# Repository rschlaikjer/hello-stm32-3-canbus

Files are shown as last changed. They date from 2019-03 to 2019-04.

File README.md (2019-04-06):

# STM32 Programming with opencm3: Part 3

This repository contains the complete companion code and KiCad design files
to accompany
[this blog post](https://rhye.org/post/stm32-with-opencm3-3-canbus/)
which works through using the CAN Bus on an STM32 series MCU.

You can also check out the three previous posts in the series:

- [Compiling and Uploading](https://rhye.org/post/stm32-with-opencm3-0-compiling-and-uploading/),
- [Alternate Functions and USARTs](https://rhye.org/post/stm32-with-opencm3-1-usart-and-printf/)
- [SPI and DMA](https://rhye.org/post/stm32-with-opencm3-2-spi-and-dma/)

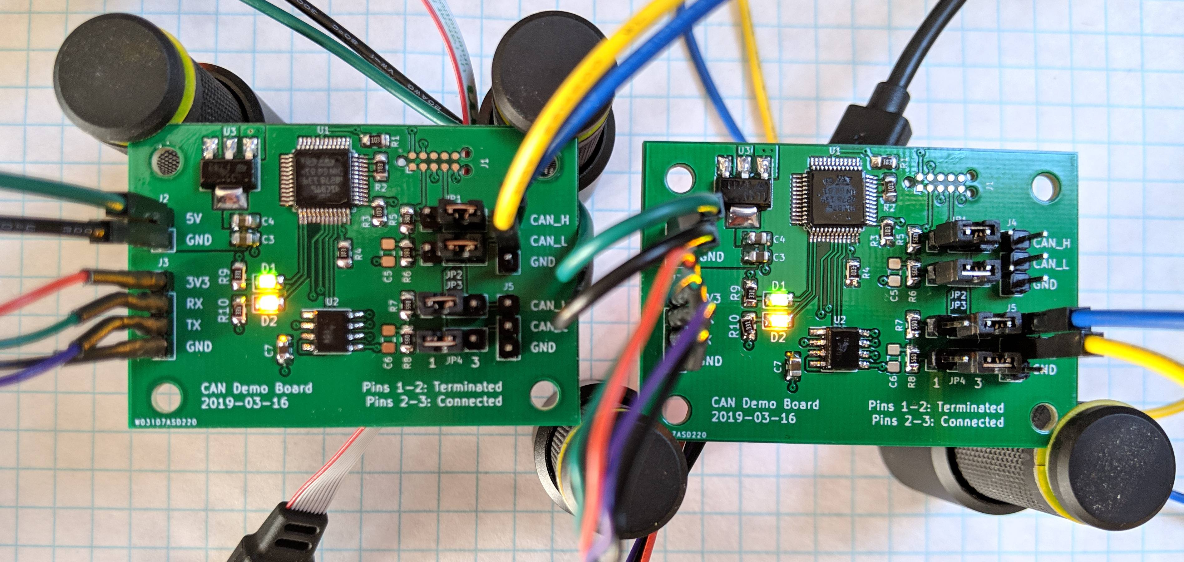
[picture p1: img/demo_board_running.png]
Blink Blink


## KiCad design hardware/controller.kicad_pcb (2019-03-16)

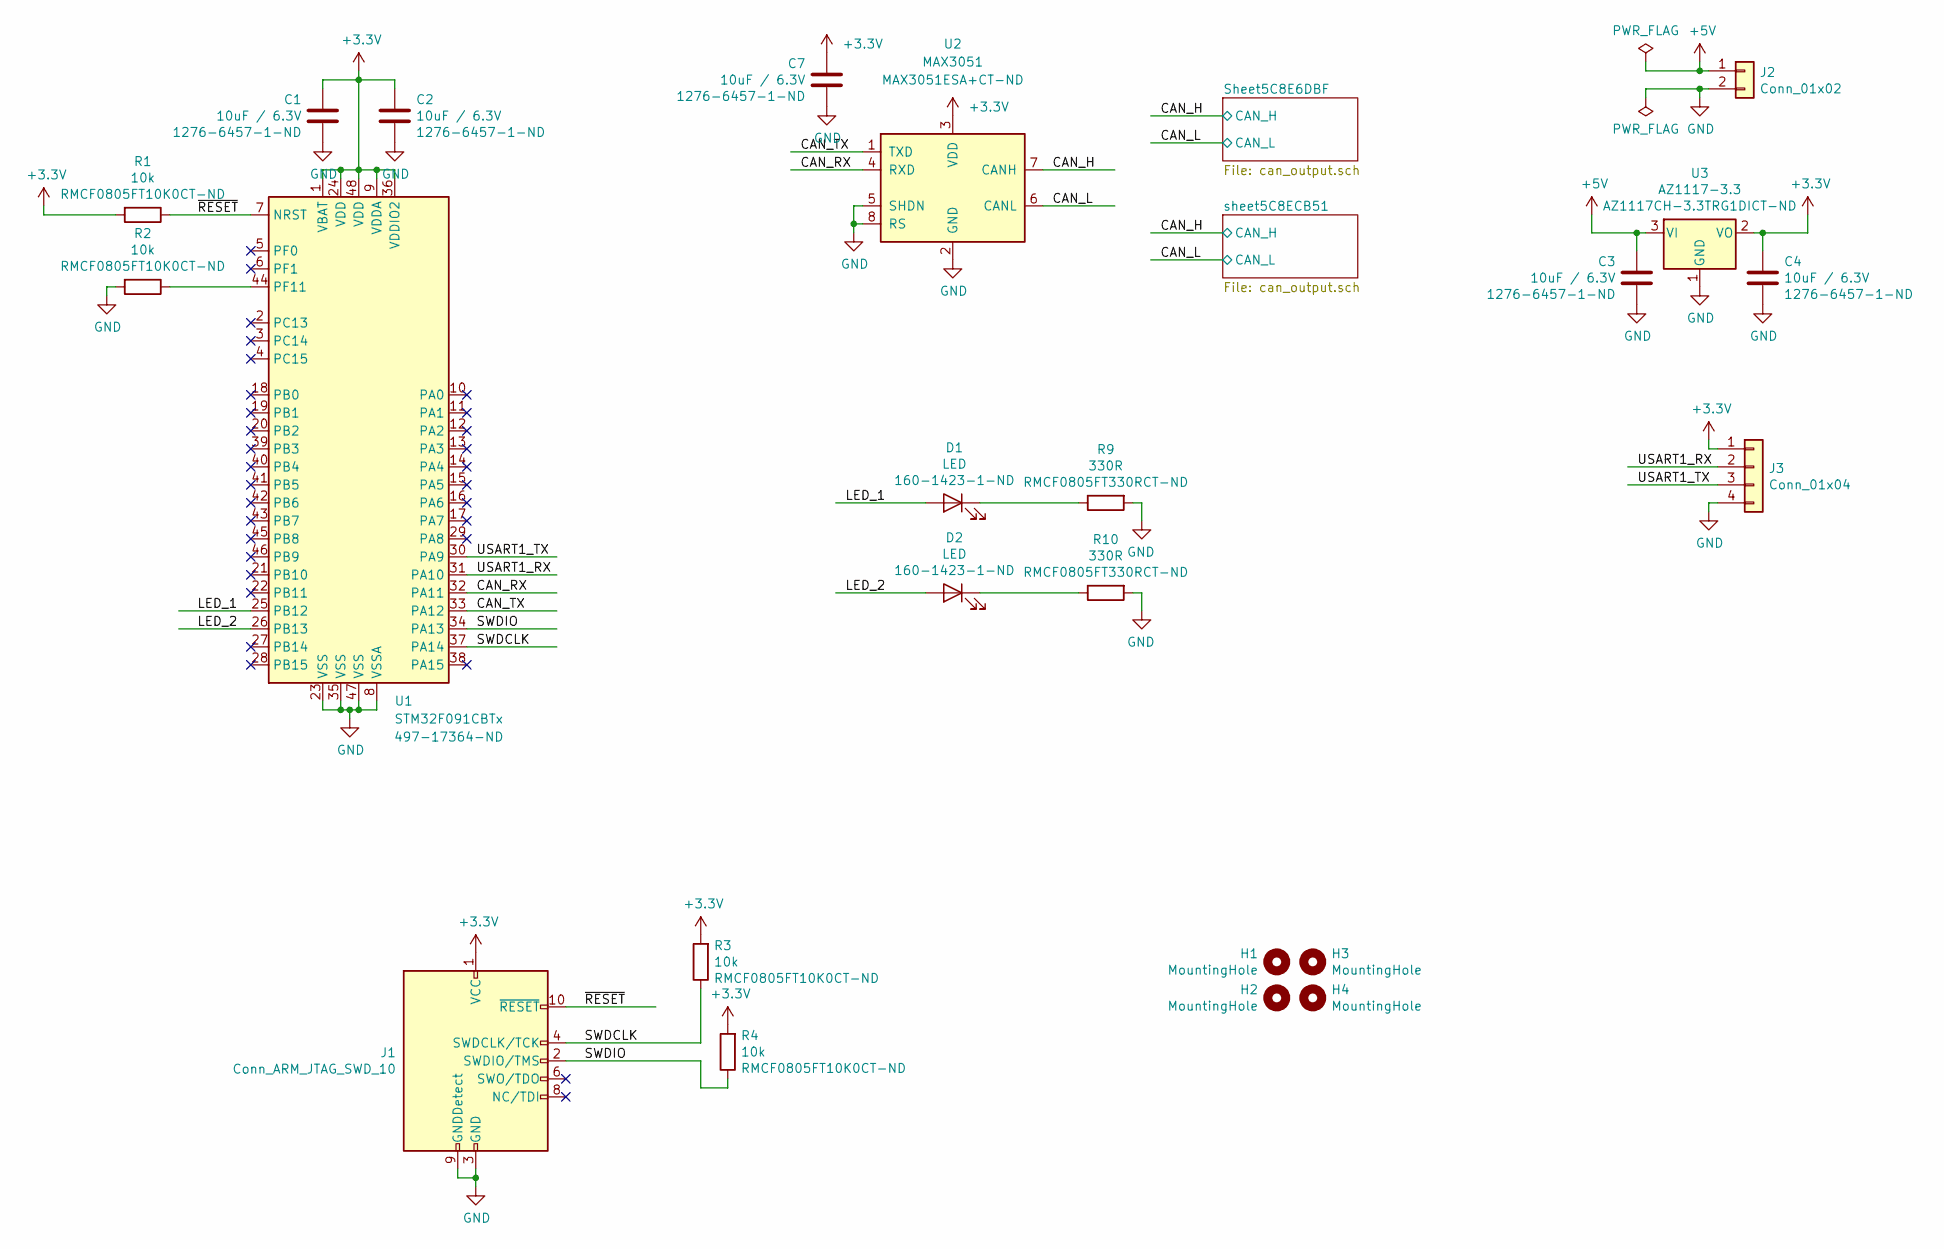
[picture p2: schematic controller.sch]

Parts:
C1, C2, C3, C4, C7: 10uF / 6.3V; C_0805_2012Metric_Pad1.15x1.40mm_HandSolder; Manufacturer PN CL21A106KQFNNNG; DigiKey PN 1276-6457-1-ND
D1, D2: LED; LED_0805_2012Metric_Pad1.15x1.40mm_HandSolder; Manufacturer PN LTST-C171GKT; DigiKey PN 160-1423-1-ND
H1, H2, H3, H4: MountingHole; MountingHole_3.2mm_M3
J1: Conn_ARM_JTAG_SWD_10; Tag-Connect_TC2050-IDC-NL_2x05_P1.27mm_Vertical
J2: Conn_01x02; PinHeader_1x02_P2.54mm_Vertical
J3: Conn_01x04; PinHeader_1x04_P2.54mm_Vertical
R1, R2, R3, R4: 10k; R_0805_2012Metric_Pad1.15x1.40mm_HandSolder; Manufacturer PN RMCF0805FT10K0; DigiKey PN RMCF0805FT10K0CT-ND
R9, R10: 330R; R_0805_2012Metric_Pad1.15x1.40mm_HandSolder; Manufacturer PN RMCF0805FT330R; DigiKey PN RMCF0805FT330RCT-ND
U1: STM32F091CBTx; LQFP-48_7x7mm_P0.5mm; Manufacturer PN STM32F091CBT6; DigiKey PN 497-17364-ND
U2: MAX3051; SOIC-8_3.9x4.9mm_P1.27mm; Manufacturer PN MAX3051ESA+T; DigiKey PN MAX3051ESA+CT-ND
U3: AZ1117-3.3; SOT-223; Manufacturer PN AZ1117CH-3.3TRG1; DigiKey PN AZ1117CH-3.3TRG1DICT-ND

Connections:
+3V3: C1.2, C2.1, C4.2, C7.1, J1.1 (VCC), J3.1, R1.2, R3.2, R4.2, U1.1 (VBAT), U1.9 (VDDA), U1.24 (VDD), U1.36 (VDDIO2), U1.48 (VDD), U2.3 (VDD), U3.2 (VO)
+5V: C3.2, J2.1, U3.3 (VI)
/CAN_H: U2.7 (CANH); also elsewhere on the board
/CAN_L: U2.6 (CANL); also elsewhere on the board
/CAN_RX: U1.32 (PA11), U2.4 (RXD)
/CAN_TX: U1.33 (PA12), U2.1 (TXD)
/LED_1: D1.2 (A), U1.25 (PB12)
/LED_2: D2.2 (A), U1.26 (PB13)
/SWDCLK: J1.4 (SWDCLK/TCK), R3.1, U1.37 (PA14)
/SWDIO: J1.2 (SWDIO/TMS), R4.1, U1.34 (PA13)
/USART1_RX: J3.2, U1.31 (PA10)
/USART1_TX: J3.3, U1.30 (PA9)
/~RESET: J1.10 (~RESET~), R1.1, U1.7 (NRST)
GND: C1.1, C2.2, C3.1, C4.1, C7.2, J1.3 (GND), J1.5 (GND), J1.9 (GNDDetect), J2.2, J3.4, R2.2, R9.2, R10.2, U1.8 (VSSA), U1.23 (VSS), U1.35 (VSS), U1.47 (VSS), U2.2 (GND), U2.5 (SHDN), U2.8 (RS), U3.1 (GND); also elsewhere on the board
unnamed: D1.1 (K), R9.1
unnamed: D2.1 (K), R10.1
unnamed: R2.1, U1.44 (PF11)

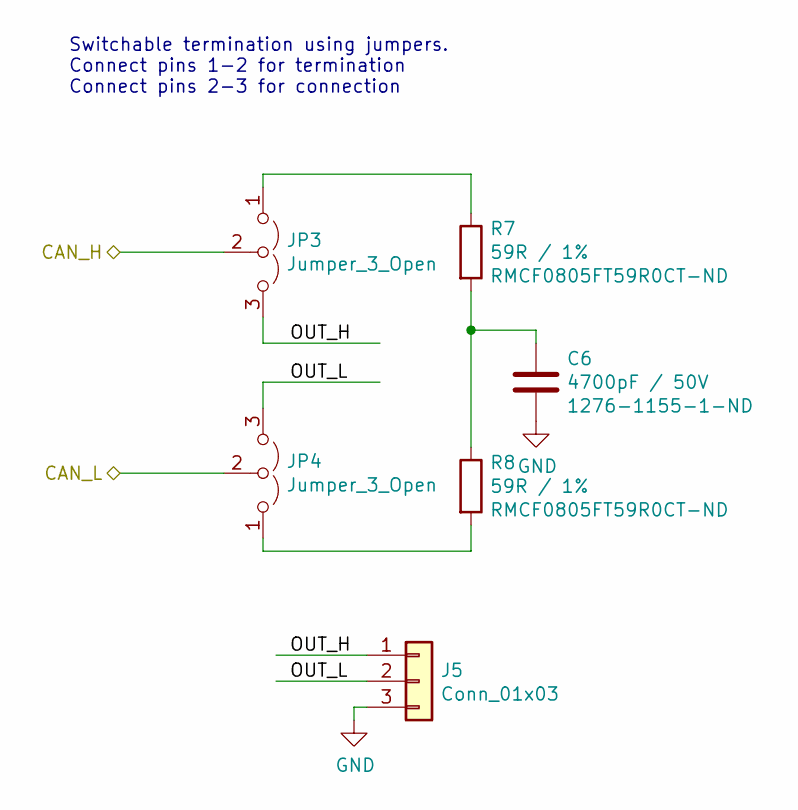
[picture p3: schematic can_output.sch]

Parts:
C5: 4700pF / 50V; C_0805_2012Metric_Pad1.15x1.40mm_HandSolder; Manufacturer PN CL21B472KBANNNC; DigiKey PN 1276-1155-1-ND
J4: Conn_01x03; PinHeader_1x03_P2.54mm_Vertical
JP1, JP2: Jumper_3_Open; PinHeader_1x03_P2.54mm_Vertical
R5, R6: 59R / 1%; R_0805_2012Metric_Pad1.15x1.40mm_HandSolder; Manufacturer PN RMCF0805FT59R0; DigiKey PN RMCF0805FT59R0CT-ND

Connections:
/CAN_H: JP1.2 (C); also elsewhere on the board
/CAN_L: JP2.2 (C); also elsewhere on the board
/Sheet5C8E6DBF/OUT_H: J4.1, JP1.3 (B)
/Sheet5C8E6DBF/OUT_L: J4.2, JP2.3 (B)
GND: C5.2, J4.3; also elsewhere on the board
unnamed: C5.1, R5.2, R6.1
unnamed: JP1.1 (A), R5.1
unnamed: JP2.1 (A), R6.2

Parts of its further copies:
C6: 4700pF / 50V; C_0805_2012Metric_Pad1.15x1.40mm_HandSolder; Manufacturer PN CL21B472KBANNNC; DigiKey PN 1276-1155-1-ND
J5: Conn_01x03; PinHeader_1x03_P2.54mm_Vertical
JP3, JP4: Jumper_3_Open; PinHeader_1x03_P2.54mm_Vertical
R7, R8: 59R / 1%; R_0805_2012Metric_Pad1.15x1.40mm_HandSolder; Manufacturer PN RMCF0805FT59R0; DigiKey PN RMCF0805FT59R0CT-ND

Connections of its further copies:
/CAN_H: JP3.2 (C); also elsewhere on the board
/CAN_L: JP4.2 (C); also elsewhere on the board
/sheet5C8ECB51/OUT_H: J5.1, JP3.3 (B)
/sheet5C8ECB51/OUT_L: J5.2, JP4.3 (B)
GND: C6.2, J5.3; also elsewhere on the board
unnamed: C6.1, R7.2, R8.1
unnamed: JP3.1 (A), R7.1
unnamed: JP4.1 (A), R8.2

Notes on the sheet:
Switchable termination using jumpers. Connect pins 1-2 for termination Connect pins 2-3 for connection

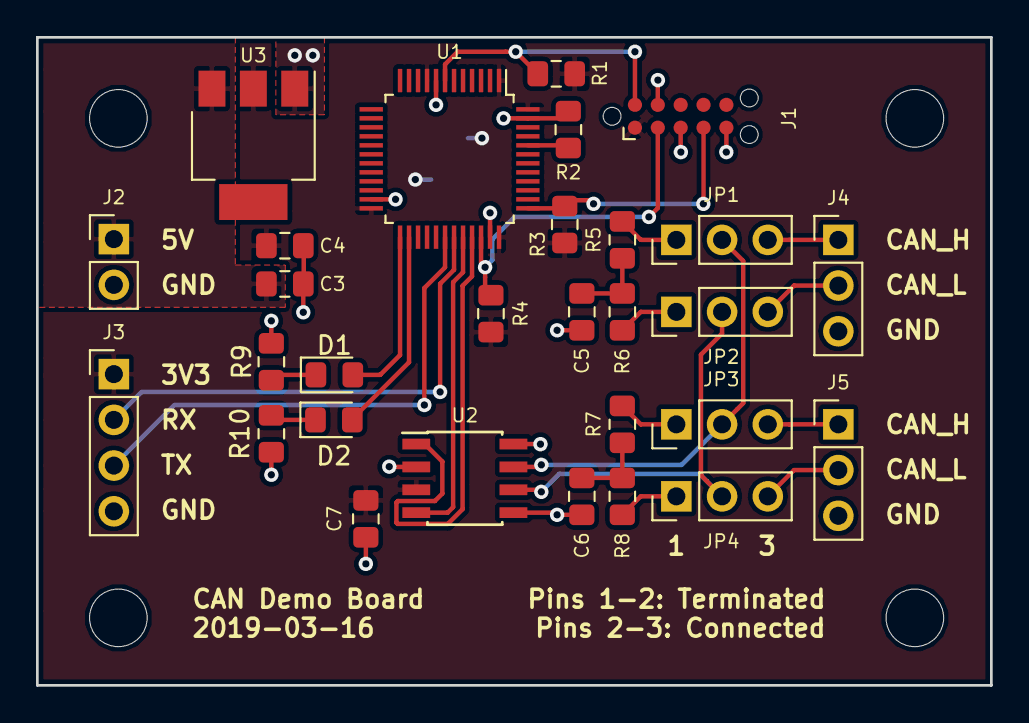
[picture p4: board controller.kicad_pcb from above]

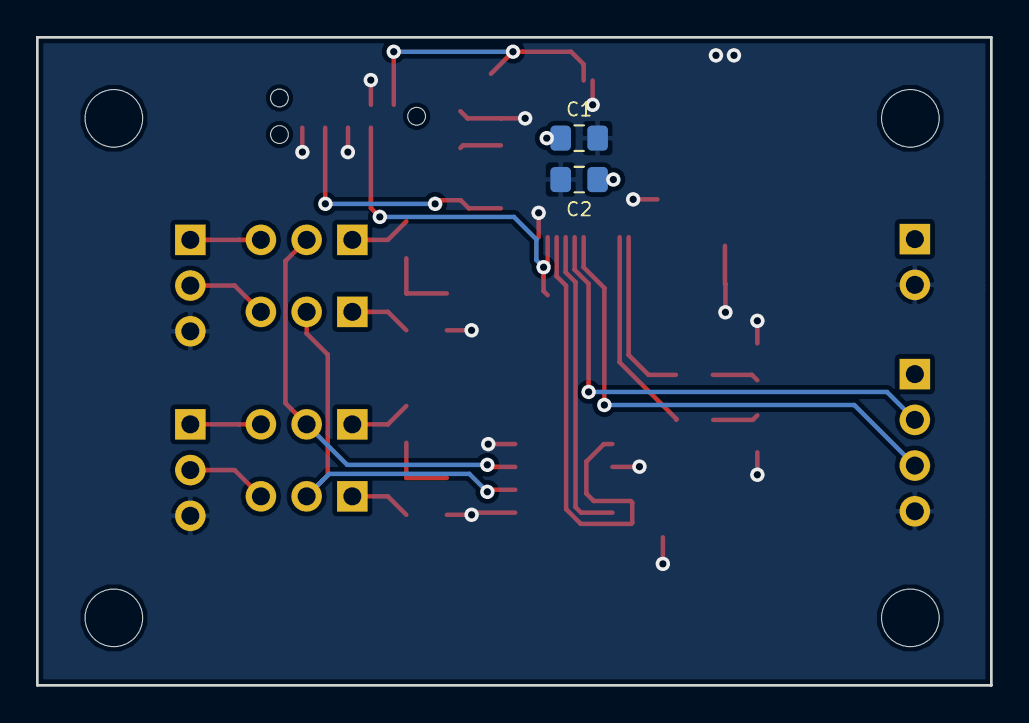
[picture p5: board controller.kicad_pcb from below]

Board: 2 copper layers, 53.0 x 36.0 mm, 35 parts (2 on the bottom side), 27 nets.

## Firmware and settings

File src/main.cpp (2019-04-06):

#include <libopencm3/stm32/gpio.h>
#include <libopencm3/stm32/rcc.h>

#include <printf.h>

#include <can.hpp>
#include <uart.hpp>

void init();
void loop();

int main() {
  init();
  while (true) {
    loop();
  }
}

void init() {
  // Configure clocks
  rcc_clock_setup_in_hsi_out_48mhz();
  rcc_periph_clock_enable(RCC_GPIOA);
  rcc_periph_clock_enable(RCC_GPIOB);

  // Initialize USART
  Uart::init();
  printf("\n\nUART Ready\n");

  // Initialize CAN peripheral
  CAN::init();
  printf("CAN Ready\n");

  gpio_mode_setup(GPIOB, GPIO_MODE_OUTPUT, GPIO_PUPD_NONE, GPIO12 | GPIO13);
  gpio_set(GPIOB, GPIO12 | GPIO13);
}

void loop() {
  // Loop over any characters pending in the UART Rx buffer,
  // and send each one over the CAN bus as a single message.
  char c;
  while (Uart::get(&c)) {
    gpio_set(GPIOB, GPIO12);
    Uart::put(c);
    CAN::Frame frame;
    frame.id = 1;
    frame.extended_id = false;
    frame.rtr = false;
    frame.len = 1;
    frame.data[0] = c;
    CAN::transmit(frame);
    gpio_clear(GPIOB, GPIO12);
  }

  // Loop over any CAN frames pending in the CAN buffer, and print out
  // the ID of the message and all the data bytes.
  CAN::Frame frame;
  while (CAN::pop(frame)) {
    gpio_set(GPIOB, GPIO13);
    // Do something with the received frame
    printf("Rx ID: %u Data: ", frame.id);
    for (int i = 0; i < frame.len; i++) {
      printf("%02x:%c", frame.data[i], frame.data[i]);
    }
    printf("\n");
    gpio_clear(GPIOB, GPIO13);
  }
}

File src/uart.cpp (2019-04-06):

#include <errno.h>
#include <stdarg.h>
#include <unistd.h>

#include <libopencm3/cm3/nvic.h>
#include <libopencm3/stm32/gpio.h>
#include <libopencm3/stm32/rcc.h>
#include <libopencm3/stm32/usart.h>

#include <printf.h>

#include <queue.hpp>

namespace Uart {

namespace {
Queue<char, 256> _tx_buffer;
Queue<char, 256> _rx_buffer;
}

void init() {
  // For the peripheral to work, we need to enable it's clock
  rcc_periph_clock_enable(RCC_USART1);
  // From the datasheet for the STM32F0 series of chips (Page 30, Table 11)
  // we know that the USART1 peripheral has it's TX line connected as
  // alternate function 1 on port A pin 9.
  // In order to use this pin for the alternate function, we need to set the
  // mode to GPIO_MODE_AF (alternate function). We also do not need a pullup
  // or pulldown resistor on this pin, since the peripheral will handle
  // keeping the line high when nothing is being transmitted.
  gpio_mode_setup(GPIOA, GPIO_MODE_AF, GPIO_PUPD_NONE, GPIO9 | GPIO10);
  // Now that we have put the pin into alternate function mode, we need to
  // select which alternate function to use. PA9 can be used for several
  // alternate functions - Timer 15, USART1 TX, Timer 1, and on some devices
  // I2C. Here, we want alternate function 1 (USART1_TX)
  gpio_set_af(GPIOA, GPIO_AF1, GPIO9 | GPIO10);
  // Now that the pins are configured, we can configure the USART itself.
  // First, let's set the baud rate at 115200
  usart_set_baudrate(USART1, 115200);
  // Each datum is 8 bits
  usart_set_databits(USART1, 8);
  // No parity bit
  usart_set_parity(USART1, USART_PARITY_NONE);
  // One stop bit
  usart_set_stopbits(USART1, USART_CR2_STOPBITS_1);
  // For a debug console, we only need unidirectional transmit
  usart_set_mode(USART1, USART_MODE_TX_RX);
  // No flow control
  usart_set_flow_control(USART1, USART_FLOWCONTROL_NONE);
  // Enable the peripheral
  usart_enable(USART1);

  // Enable interrupts for tx/rx
  nvic_enable_irq(NVIC_USART1_IRQ);
  usart_enable_rx_interrupt(USART1);
  usart_enable_tx_interrupt(USART1);
}

void put(char c) {
  _tx_buffer.push(c);
  usart_enable_tx_interrupt(USART1);
}

bool get(char *c) { return _rx_buffer.pop(*c); }

void flush() {
  while (_tx_buffer.available()) {
  }
}

void isr() {
  // Check if interrupt is signalling TX ready
  if (usart_get_flag(USART1, USART_FLAG_TXE)) {
    // Try and pop a byte from the tx buffer
    char c;
    if (_tx_buffer.pop(c)) {
      // Move the next byte of data to the tx buffer
      usart_send(USART1, c);
    } else {
      // If there's no more data to be sent, disable this interrupt
      usart_disable_tx_interrupt(USART1);
    }
  }

  // Check if data has been received (RX Not Empty)
  if (usart_get_flag(USART1, USART_FLAG_RXNE)) {
    const uint16_t c = usart_recv(USART1);
    // Might fail if buffer is full!
    _rx_buffer.push(c);
  }
}

} // namespace Uart

void _putchar(char c) {
  if (c == '\n') {
    Uart::put('\r');
  }
  Uart::put(c);
}

void usart1_isr(void) { Uart::isr(); }

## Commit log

2019-03-16 Add printf submodule
2019-03-16 Demo board kicad
    [can_output.sch, controller.kicad_pcb, controller.sch]
2019-04-06 Pipe UART input over CANbus
2019-04-06 Add readme, gerbers
    [controller-B.Cu.gbl, controller-B.Mask.gbs, controller-B.Paste.gbp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]
